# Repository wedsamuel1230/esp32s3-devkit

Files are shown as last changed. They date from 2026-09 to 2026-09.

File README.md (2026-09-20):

# ESP32-S3 Custom Development Board

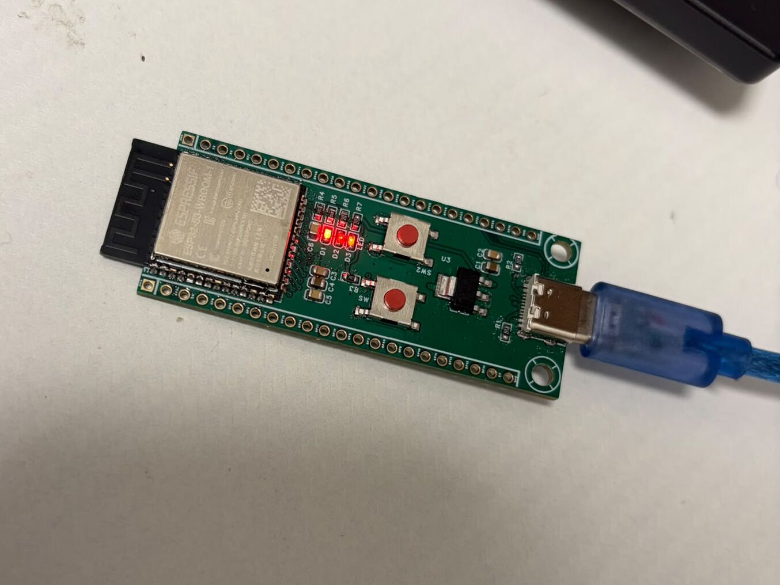
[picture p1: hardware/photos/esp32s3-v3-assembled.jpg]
Assembled ESP32-S3 v3 board


> This repository is a working record of a custom ESP32-S3 board.
> It keeps the source files, design changes, test notes, and open work.

## Record status

| Item | Current record |
|---|---|
| Board revision | v3 |
| Main module | ESP32-S3-WROOM-1-N16R8 |
| PCB | 4 layers, 1.6 mm finished thickness |
| CAD source | EasyEDA Pro project archive |
| Board state | Assembled board photo is available |
| Test state | Some bring-up results are recorded; more tests are open |

This is not a claim that every test is complete. Read the [engineering record](docs/engineering-record.md) for the details.

## What this board is

This board is a small ESP32-S3 development board. It has:

- ESP32-S3-WROOM-1-N16R8
- USB-C power and native USB
- 3.3 V LDO power
- GPIO0 BOOT button
- EN/RESET button
- GPIO21 status LED
- Two 1×22 headers with 2.54 mm pitch
- Four-layer PCB routing

## Start here

1. Read the [engineering record](docs/engineering-record.md).
2. Open the [EasyEDA Pro source](hardware/easyeda/esp32s3-devkit-v3.epro2).
3. View the [schematic PDF](hardware/schematic/esp32s3-v3-schematic.pdf).
4. Check the [PCB layout image](hardware/renders/esp32s3-v3-pcb-layout.png).
5. Read the [EasyEDA source notes](hardware/easyeda/README.md).

The `.epro2` file is the editable source. PDF, PNG, Gerber, and STEP files are exports. Use them to view or make the board. Do not use them as the main source.

## Revision record

| Revision | Main change | Record result |
|---|---|---|
| v1 | Two-layer Eagle board with narrow power traces | Brownout and reset problems were recorded during radio activity |
| v2 | EasyEDA version with new power and USB work | USB, power, reset, and antenna problems were recorded |
| v3 | Four-layer EasyEDA board | Better power routing, corrected USB mapping, longer EN delay, and multi-layer antenna keep-out |

The full change notes are in the [engineering record](docs/engineering-record.md).

## Current test record

| Test | Status | Evidence in this repository |
|---|---|---|
| 3.3 V rail | Reported in the project record | No saved measurement log yet |
| Native USB Serial/JTAG | Reported in the project record | No saved host log yet |
| GPIO21 LED | Reported in the project record | Firmware is included |
| Wi-Fi scan | Open | Firmware is included; board test is not recorded |
| Cold continuity checks | Open | Bring-up list is in the engineering record |
| Rail scope check during radio activity | Open | No scope capture is included |
| ERC and DRC report | Not recorded | No report is included |
| Full production release check | Open | Do not treat this repository as a production release |

## Important layout notes

- GPIO19 is USB D-.
- GPIO20 is USB D+.
- The USB pair uses 8 mil trace width and 6 mil spacing in the recorded layout.
- The pair targets 90 Ω differential impedance. This target is not a measured result.
- L2 is the ground reference below the USB pair.
- The ESP32-S3 antenna area is cleared on all four board layers.
- GPIO0 is a boot strap pin. Check the pin before connecting external circuits.
- GPIO19 and GPIO20 are shared with USB. External loads can affect USB.

## Files

| File | Use |
|---|---|
| [`hardware/easyeda/esp32s3-devkit-v3.epro2`](hardware/easyeda/esp32s3-devkit-v3.epro2) | Editable EasyEDA Pro source |
| [`hardware/schematic/esp32s3-v3-schematic.pdf`](hardware/schematic/esp32s3-v3-schematic.pdf) | Schematic for reading |
| [`hardware/bom/esp32s3-v3-bom.xlsx`](hardware/bom/esp32s3-v3-bom.xlsx) | Bill of materials |
| [`hardware/gerber/esp32s3-v3-gerbers.zip`](hardware/gerber/esp32s3-v3-gerbers.zip) | PCB manufacturing files |
| [`hardware/mechanical/esp32s3-v3.step`](hardware/mechanical/esp32s3-v3.step) | 3D board model |
| [`hardware/renders/esp32s3-v3-pcb-layout.png`](hardware/renders/esp32s3-v3-pcb-layout.png) | PCB layout view |
| [`hardware/renders/esp32s3-v3-render.png`](hardware/renders/esp32s3-v3-render.png) | 3D board view |
| [`firmware/arduino/blink_and_scan/blink_and_scan.ino`](firmware/arduino/blink_and_scan/blink_and_scan.ino) | LED, USB, and Wi-Fi test |

## Firmware test

The Arduino sketch does three things:

1. blinks the GPIO21 LED;
2. prints messages over USB serial at 115200 baud;
3. starts a Wi-Fi scan every 15 seconds.

The Wi-Fi result is still open. A sketch in the repository does not prove that the assembled board passed the test.

## How to add a record entry

For each hardware change, record:

- date and revision;
- what changed;
- why it changed;
- what file or measurement supports it;
- result;
- next check or open question.

Keep one change in one Git commit when possible. Use a clear commit message. This makes the board history easier to read.

Use the template at the end of [`docs/engineering-record.md`](docs/engineering-record.md).

## License

The current [`LICENSE`](LICENSE) file covers the software and documentation. It does not clearly set a license for the PCB files. Add a hardware license before making a final open-hardware claim.

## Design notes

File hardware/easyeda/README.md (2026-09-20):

# EasyEDA Pro source

`esp32s3-devkit-v3.epro2` is the native EasyEDA Pro project archive for the v3 board.

## Open the source

Open the archive with EasyEDA Pro using its project import/open flow. Keep the archive as one unit in the GitHub repository. The archive is not intended to be edited as a collection of manually extracted files, and the internal `.epru` data should not be edited with a text editor.

The companion files in `hardware/` are readable exports and review evidence:

- [schematic PDF](../schematic/esp32s3-v3-schematic.pdf)
- [BOM](../bom/esp32s3-v3-bom.xlsx)
- [Gerber archive](../gerber/esp32s3-v3-gerbers.zip)
- [STEP model](../mechanical/esp32s3-v3.step)
- [PCB layout render](../renders/esp32s3-v3-pcb-layout.png)
- [assembled-board photo](../photos/esp32s3-v3-assembled.jpg)

## Source audit

The archive was inspected locally on 2026-09-20. Its top-level project metadata identifies EasyEDA Pro editor version `3.2.203`. The archive contains one schematic document, one PCB document, embedded device/footprint data, and nine WebP image assets. No password, API key, private-key marker, or similar credential string was found during the local archive scan.

This is a structural audit only. The project was not opened in the EasyEDA Pro editor in this environment, so successful interactive import, schematic-to-PCB parity, DRC, and fabrication readiness remain separate checks.

## Integrity

SHA-256:

```text
87307733b983e868c155da1e48b15ecf7174de0ee3033b91b34138fb87811d07  esp32s3-devkit-v3.epro2
```

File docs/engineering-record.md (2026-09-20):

# Engineering Record

This page records the board work. It keeps changes, reasons, evidence, results, and open questions together.

The record uses four simple labels:

- **Observed**: seen in a file, image, or direct test.
- **Reported**: written in the project notes, but the raw test log is not in this repository.
- **Open**: the test or work is not complete.
- **Not recorded**: this repository has no evidence for it yet.

## Record rules

For each new entry, write:

1. date and revision;
2. change;
3. reason;
4. evidence;
5. result;
6. next check.

Keep observations separate from guesses. Keep a design target separate from a measured result. Use one Git commit for one related change when possible.

## Project baseline

### 2026-09-20 — v3 source package

**Change**

Saved the EasyEDA Pro project archive in the repository:

[`hardware/easyeda/esp32s3-devkit-v3.epro2`](../hardware/easyeda/esp32s3-devkit-v3.epro2)

**Reason**

The native project file is needed for later schematic and PCB changes. PDF and Gerber files alone cannot be used as the main editable source.

**Observed**

- The archive has one schematic document and one PCB document.
- It has embedded device and footprint data.
- It has nine WebP image assets.
- The archive metadata names EasyEDA Pro editor version `3.2.203`.
- The archive passes a local ZIP integrity check.
- SHA-256: `87307733b983e868c155da1e48b15ecf7174de0ee3033b91b34138fb87811d07`.

**Not recorded**

- EasyEDA Pro GUI import was not checked in this environment.
- No fresh ERC or DRC report is in this repository.
- No oscilloscope capture, continuity log, or host USB log is in this repository.

## Revision history

### v1 — two-layer Eagle board

**Change**

The first board used a two-layer Autodesk Eagle layout. The 5 V and 3.3 V paths used about 6–8 mil traces.

**Reason for the next change**

The project notes report brownout and reset problems during radio activity. The narrow power paths were treated as a possible source of transient voltage drop.

**Record result**

The v1 board was not kept as the current design.

### v2 — EasyEDA board

**Change**

The design moved to EasyEDA. The project notes report these problems:

- USB D+ and D- were crossed.
- The LD1117 regulator had less input margin.
- The EN network used 10 kΩ and 100 nF, about 1 ms nominal RC time.
- The antenna keep-out did not cover all board layers.

**Record result**

The project notes report repeated USB connect/disconnect and enumeration failure.

### v3 — four-layer EasyEDA board

**Change**

The v3 layout uses:

- four layers;
- about 1.6 mm finished board thickness;
- JLC04161H-7628 stackup;
- 1 oz outer copper and 0.5 oz inner copper;
- ME6118A33B3G 3.3 V LDO;
- 10 kΩ and 1 µF EN network, about 10 ms nominal RC time;
- GPIO19 to USB D-;
- GPIO20 to USB D+;
- 8 mil USB trace width;
- 6 mil USB pair spacing;
- no more than 10 mil recorded intra-pair mismatch;
- antenna copper clearance on all four layers.

**Record result**

The project record reports a stable 3.30 V rail, native USB Serial/JTAG enumeration, and GPIO21 LED operation on the assembled v3 board.

These are reported results. This repository does not contain the raw measurement files yet.

## Layout decisions

### Power

**Change**

The v3 design uses wider power paths, local ceramic capacitors, and a larger bulk capacitor on the 3.3 V rail.

**Reason**

ESP32-S3 radio activity can create fast current changes. A board can pass an idle check and still have a short rail drop during radio activity.

**Next check**

Measure 3V3 at the ESP32 module pins during reset and Wi-Fi activity. Save the scope capture with the board revision and test setup.

### USB

**Change**

The recorded v3 mapping is:

```text
GPIO19 -> USB D-
GPIO20 -> USB D+
```

The pair is routed over the L2 ground reference.

**Reason**

The v2 record reports a crossed pair. The v3 layout keeps the pair together and keeps the reference plane under it.

**Design target**

The route uses 8 mil width and 6 mil spacing to target 90 Ω differential impedance on the selected stackup.

**Limit**

The 90 Ω value is a design target. It is not a TDR measurement in this repository.

### Reset and boot

**Change**

The EN network uses a 10 kΩ pull-up and a 1 µF capacitor. GPIO0 is used for BOOT control.

**Reason**

The v3 record uses a longer nominal RC time than v2 to give the 3.3 V rail more time to settle.

**Next check**

Check EN during power-up. Check that holding GPIO0 low before reset enters download mode.

### RF keep-out

**Change**

The antenna area under the ESP32-S3 module is cleared on Top, L2, L3, and Bottom.

**Reason**

Copper below a module antenna can change the RF environment. The keep-out must cover the full board stack.

**Next check**

Run the Wi-Fi scan on the assembled board. Record the scan result, reset count, and test power source.

## Bring-up record

| Test | Status | Evidence needed to close it |
|---|---|---|
| 5 V to GND short check | Open | Resistance value and board photo or test note |
| 3V3 to GND short check | Open | Resistance value after capacitors settle |
| USB D- to GPIO19 | Open | Continuity measurement |
| USB D+ to GPIO20 | Open | Continuity measurement |
| D+ and D- not shorted | Open | Continuity measurement |
| 3.30 V at module pins | Reported | Saved meter or scope record |
| 3.3 V during radio activity | Open | Scope capture at the module pins |
| EN reset timing | Open | Scope capture or clear test note |
| BOOT download mode | Open | Host log or test note |
| Native USB enumeration | Reported | Saved host log with board revision |
| GPIO21 LED | Reported | Firmware output or test photo |
| Wi-Fi scan | Open | Serial log and reset count |
| ERC | Not recorded | Fresh EasyEDA Pro ERC report |
| DRC | Not recorded | Fresh EasyEDA Pro DRC report |
| Fabrication readiness | Open | Source, checks, export review, and physical fit evidence |

## Files for this record

- [EasyEDA Pro source](../hardware/easyeda/esp32s3-devkit-v3.epro2)
- [Schematic PDF](../hardware/schematic/esp32s3-v3-schematic.pdf)
- [BOM](../hardware/bom/esp32s3-v3-bom.xlsx)
- [Gerber archive](../hardware/gerber/esp32s3-v3-gerbers.zip)
- [STEP model](../hardware/mechanical/esp32s3-v3.step)
- [PCB layout image](../hardware/renders/esp32s3-v3-pcb-layout.png)
- [3D render](../hardware/renders/esp32s3-v3-render.png)
- [Arduino test sketch](../firmware/arduino/blink_and_scan/blink_and_scan.ino)

## Why this record has this shape

The root README is the short entry page. This file holds the longer history.

The method follows two simple ideas:

- Keep the native source with the project. Keep PDF, Gerber, BOM, and photos as easy-to-view helper files.
- For each change, write what changed, why, what supports it, what happened, and what is still open.

The first idea follows the [OSHWA open hardware definition](https://oshwa.org/definition/) and its [sharing best practices](https://oshwa.org/resources/sharing-best-practices/). The second idea fits GitHub's use of commits to show who changed what and why. See [GitHub README guidance](https://docs.github.com/en/repositories/managing-your-repositorys-settings-and-features/customizing-your-repository/about-readmes) and [GitHub commit guidance](https://docs.github.com/en/pull-requests/reference/commits).

## New entry template

Copy this block for the next hardware change:

```markdown
## YYYY-MM-DD — revision or test name

**Change**

What changed?

**Reason**

Why was it changed?

**Evidence**

Which file, measurement, photo, or log supports the entry?

**Result**

What happened? Use `reported`, `checked`, `open`, or `failed` when useful.

**Next check**

What is still unknown or what should happen next?
```

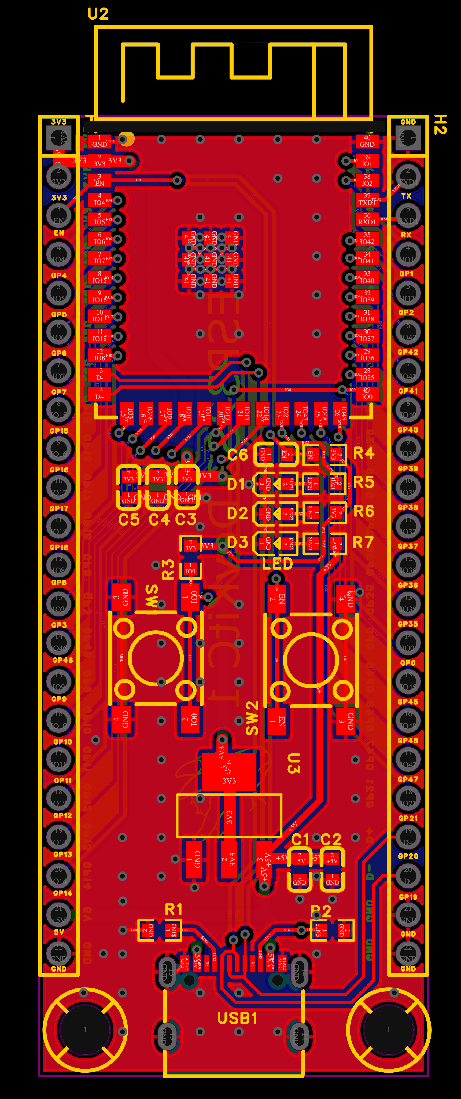
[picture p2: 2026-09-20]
hardware/renders/esp32s3-v3-pcb-layout.png

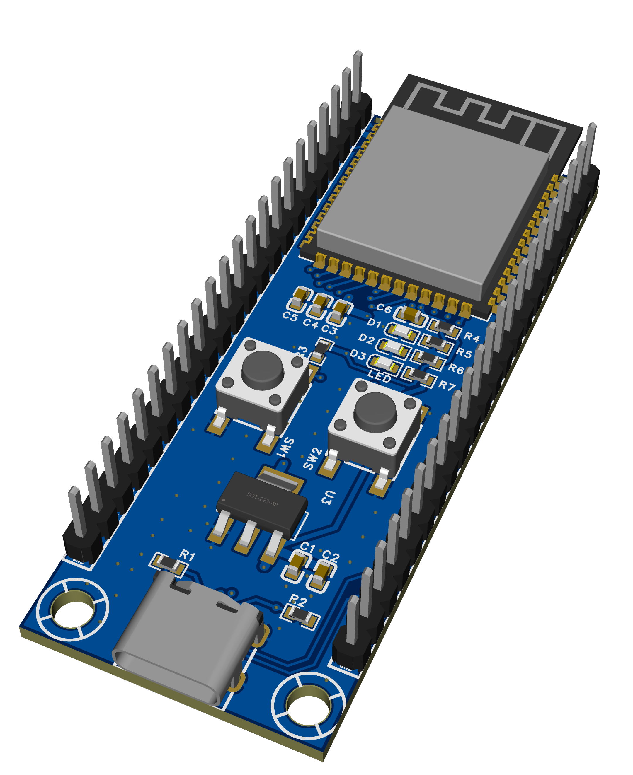
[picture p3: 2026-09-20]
hardware/renders/esp32s3-v3-render.png

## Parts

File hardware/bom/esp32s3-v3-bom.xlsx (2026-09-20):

No. | Quantity | Comment | Designator | Footprint | Value | Manufacturer Part | Manufacturer | Supplier Part | Supplier
1 | 2 | 10uF | C1,C4 | C0603 | 10uF
2 | 2 | 100nF | C2,C3 | C0603 | 100nF
3 | 1 | 22uF | C5 | C0603 | 22uF
4 | 1 | 1uF | C6 | C0603 | 1uF
5 | 3 | XL-1608SURC-06 | D1,D2,D3 | LED0603-RD_RED |  | XL-1608SURC-06 | XINGLIGHT(成兴光) | C965799 | LCSC
6 | 2 | HC-PZ254-11.5L-1x22PZ | H1,H2 | HDR-TH_22P-P2.54-V-M |  | HC-PZ254-11.5L-1x22PZ | HC(虹成电子) | C41375941 | LCSC
7 | 2 | 5.1K | R1,R2 | R0603 | 5.1K
8 | 2 | 10K | R3,R4 | R0603 | 10K
9 | 3 | 1K | R5,R6,R7 | R0603 | 1K
10 | 2 | M3螺丝 | SCREW1,SCREW2 | M3螺丝
11 | 2 | TSD003B05026A46 | SW1,SW2 | SW-SMD_4P-L6.0-W6.0-P4.50-LS8.6 |  | TSD003B05026A46 | BZCN(博众电气) | C2888760 | LCSC
12 | 1 | 2.4GHz | U2 | WIRELM-SMD_ESP32-S3-WROOM-1 | 2.4GHz | ESP32-S3-WROOM-1-N16R8 | ESPRESSIF(乐鑫) | C2913202 | LCSC
13 | 1 | ME6118A33B3G | U3 | SOT-223_L6.5-W3.5-P2.30-LS7.0-BR |  | ME6118A33B3G | MICRONE(南京微盟) | C151063 | LCSC
14 | 1 | TYPE-C 16PIN 2MD(073) | USB1 | USB-C-SMD_TYPE-C-16PIN-2MD-073 |  | TYPE-C 16PIN 2MD(073) | SHOU HAN(首韩) | C2765186 | LCSC

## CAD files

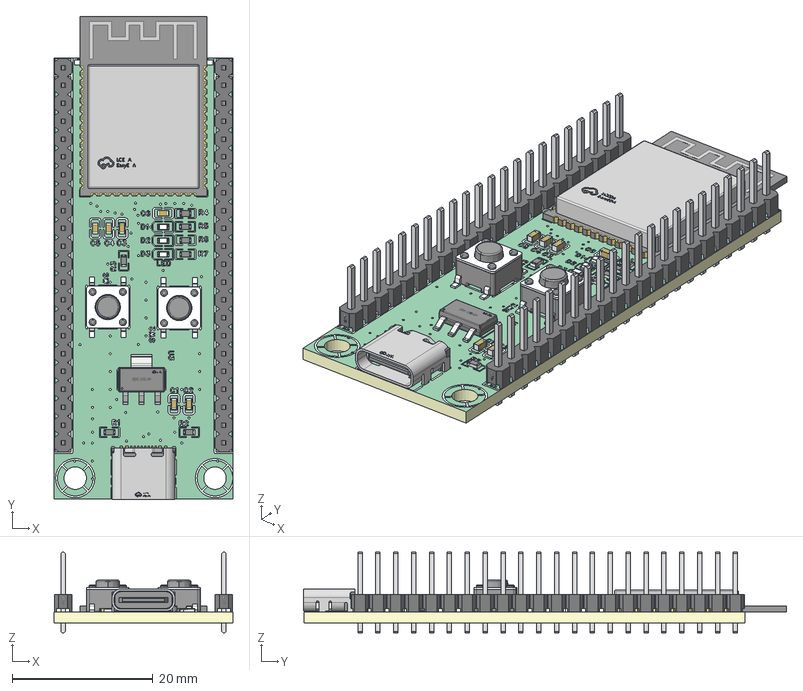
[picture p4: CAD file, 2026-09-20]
hardware/mechanical/esp32s3-v3.step
25.4 x 68.6 x 11.5 mm
Board~K6f7
TopCopper~K6f7
BottomCopper~K6f7
TopSilkscreen~K6f7 x 265
BottomSilkscreen~K6f7 x 171
TopFpcStiffener~K6f7
BottomFpcStiffener~K6f7
C0603~C0603_L1.6-W0.8-H0.8~QjcB x 6
LED0603-RD_RED~LED0603-RD_RED~Cohz x 3
USB-C-SMD_TYPE-C-16PIN-2MD-073~USB-C-SMD_TYPE-C-6PIN-2MD-073~ToD7
SOT-223_L6.5-W3.5-P2.30-LS7.0-BR~SOT-223-4P_L6.5-W3.5-H1.6-LS7.0-P2.30~r51p
WIRELM-SMD_ESP32-S3-WROOM-1~WIRELM-SMD_ESP32-S3-WROOM-1~luiC
R0603~R0603~rTn4 x 7
SW-SMD_4P-L6.0-W6.0-P4.50-LS8.6~SW-SMD_4P-L6.0-W6.0-P4.50-LS8.6~CHqz x 2
HDR-TH_22P-P2.54-V-M~HDR-TH_22P-P2.54-M-LI-1X22P~SIXE x 2

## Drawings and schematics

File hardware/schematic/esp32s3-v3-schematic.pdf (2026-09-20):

IO0 27 IO35 28 IO36 29 IO37 30 IO38 31 IO39 32 IO40 33 IO41 34 IO42 35 RXD0 36 TXD0 37 IO2 38 IO1 39 GND 40

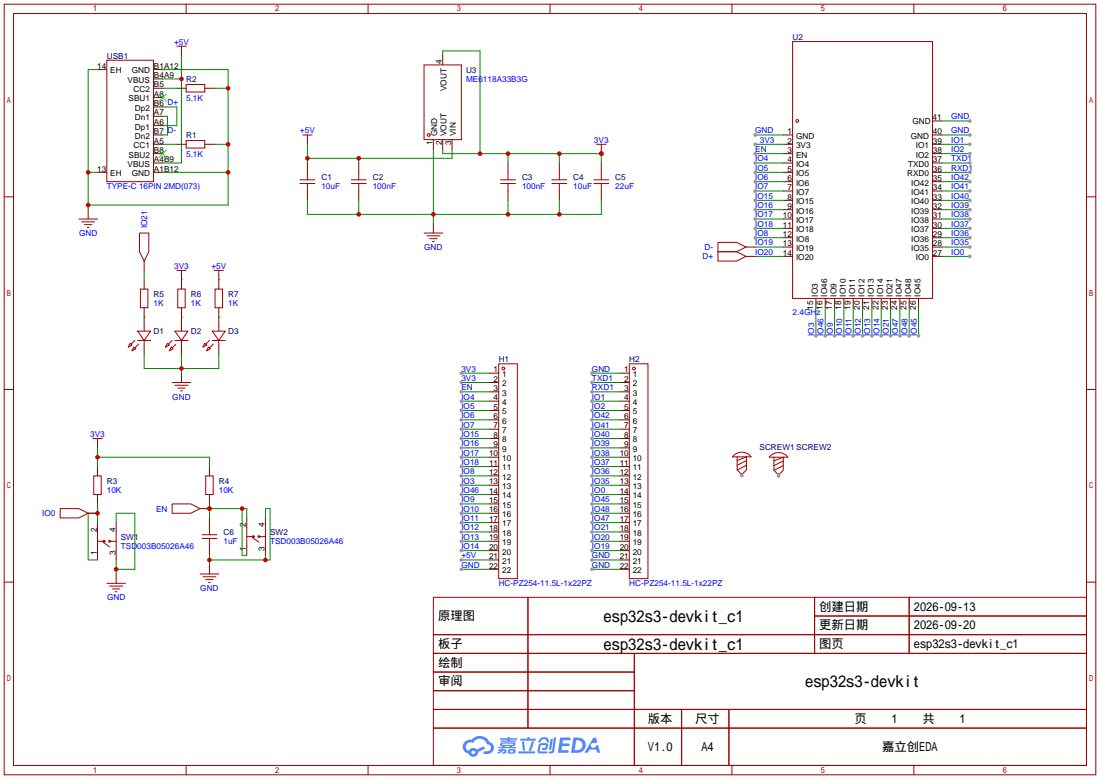
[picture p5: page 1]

USB1
GND A1B12 VBUS A4B9 SBU2 B8 CC1 A5 Dn2 B7 Dp1 A6 Dn1 A7 Dp2 B6 SBU1 A8 CC2 B5 VBUS B4A9 GND B1A12 EH 14

原理图 | esp32s3-devkit_c1 | 创建日期 | 2026-09-13

更新日期 | 2026-09-20

板子 | esp32s3-devkit_c1 | 图页 | esp32s3-devkit_c1
绘制 | | esp32s3-devkit
审阅

V1.0 | A4 | 嘉立创EDA

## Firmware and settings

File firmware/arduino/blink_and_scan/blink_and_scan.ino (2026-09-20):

#include <Arduino.h>
#include <WiFi.h>

namespace {

constexpr gpio_num_t kLedPin = GPIO_NUM_21;
constexpr uint32_t kSerialBaud = 115200;
constexpr uint32_t kBlinkIntervalMs = 500;
constexpr uint32_t kScanIntervalMs = 15000;

bool ledState = false;
bool scanInProgress = false;
uint32_t lastBlinkMs = 0;
uint32_t lastScanStartMs = 0;

void serviceLed() {
  const uint32_t now = millis();
  if (now - lastBlinkMs < kBlinkIntervalMs) {
    return;
  }

  lastBlinkMs = now;
  ledState = !ledState;
  digitalWrite(static_cast<uint8_t>(kLedPin), ledState ? HIGH : LOW);
}

void printScanResults(int networkCount) {
  Serial.println();

  if (networkCount <= 0) {
    Serial.println("[WiFi] Scan complete: no networks found.");
    return;
  }

  Serial.printf("[WiFi] Scan complete: %d network(s)\n", networkCount);
  Serial.println("  # | RSSI      | CH | Security | SSID");
  Serial.println("----+-----------+----+----------+------------------------------");

  for (int i = 0; i < networkCount; ++i) {
    const char *security = "open";
    if (WiFi.encryptionType(i) != WIFI_AUTH_OPEN) {
      security = "secured";
    }

    Serial.printf(
        "%3d | %4d dBm | %2d | %-8s | %s\n",
        i + 1,
        WiFi.RSSI(i),
        WiFi.channel(i),
        security,
        WiFi.SSID(i).c_str());
  }
}

void startScan() {
  WiFi.scanDelete();

  // async=true, show_hidden=true.
  const int result = WiFi.scanNetworks(true, true);
  if (result == WIFI_SCAN_FAILED) {
    Serial.println("[WiFi] Failed to start scan.");
    scanInProgress = false;
    return;
  }

  scanInProgress = true;
  lastScanStartMs = millis();
  Serial.println("[WiFi] 2.4 GHz scan started...");
}

void serviceWifiScan() {
  if (!scanInProgress) {
    if (millis() - lastScanStartMs >= kScanIntervalMs) {
      startScan();
    }
    return;
  }

  const int result = WiFi.scanComplete();
  if (result == WIFI_SCAN_RUNNING) {
    return;
  }

  if (result == WIFI_SCAN_FAILED) {
    Serial.println("[WiFi] Scan failed.");
  } else {
    printScanResults(result);
  }

  WiFi.scanDelete();
  scanInProgress = false;
  lastScanStartMs = millis();
}

}  // namespace

void setup() {
  pinMode(static_cast<uint8_t>(kLedPin), OUTPUT);
  digitalWrite(static_cast<uint8_t>(kLedPin), LOW);

  // On ESP32-S3, enable "USB CDC On Boot" in the board configuration so
  // Serial is carried by the native USB connector.
  Serial.begin(kSerialBaud);

  const uint32_t serialWaitStart = millis();
  while (!Serial && millis() - serialWaitStart < 3000) {
    serviceLed();
    delay(10);
  }

  Serial.println();
  Serial.println("ESP32-S3 v3 board verification");
  Serial.println("Native USB CDC serial online.");
  Serial.println("GPIO21 status LED enabled.");

  WiFi.mode(WIFI_STA);

  // Stay disconnected from an AP; this program only verifies reception.
  WiFi.disconnect(false, false);
  delay(100);

  Serial.print("Wi-Fi STA mode enabled. Station MAC: ");
  Serial.println(WiFi.macAddress());

  // Start immediately; later scans run every kScanIntervalMs after completion.
  lastScanStartMs = millis() - kScanIntervalMs;
}

void loop() {
  serviceLed();
  serviceWifiScan();
  delay(1);
}
